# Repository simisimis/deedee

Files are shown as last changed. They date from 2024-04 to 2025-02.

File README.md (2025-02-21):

# DeeDee

A 36+2 key split monoblock ortholinear keyboard

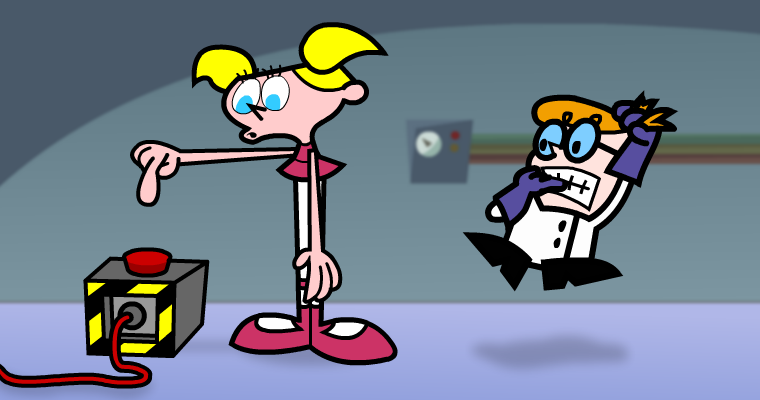
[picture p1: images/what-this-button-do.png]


## Current progress:

- [x] Key matrix
- [x] Layout defined
- [x] Addressable LEDs
- [x] Rotary encoders
- [ ] SSD1306 OLED screen
- [ ] Cirque touchpad
- [ ] Case design

A place where I try to document every step of the process is journalled in my [Project blog posts](https://github.com/simisimis/project-blog/tree/main/projects/DIY-keyboard) repo.

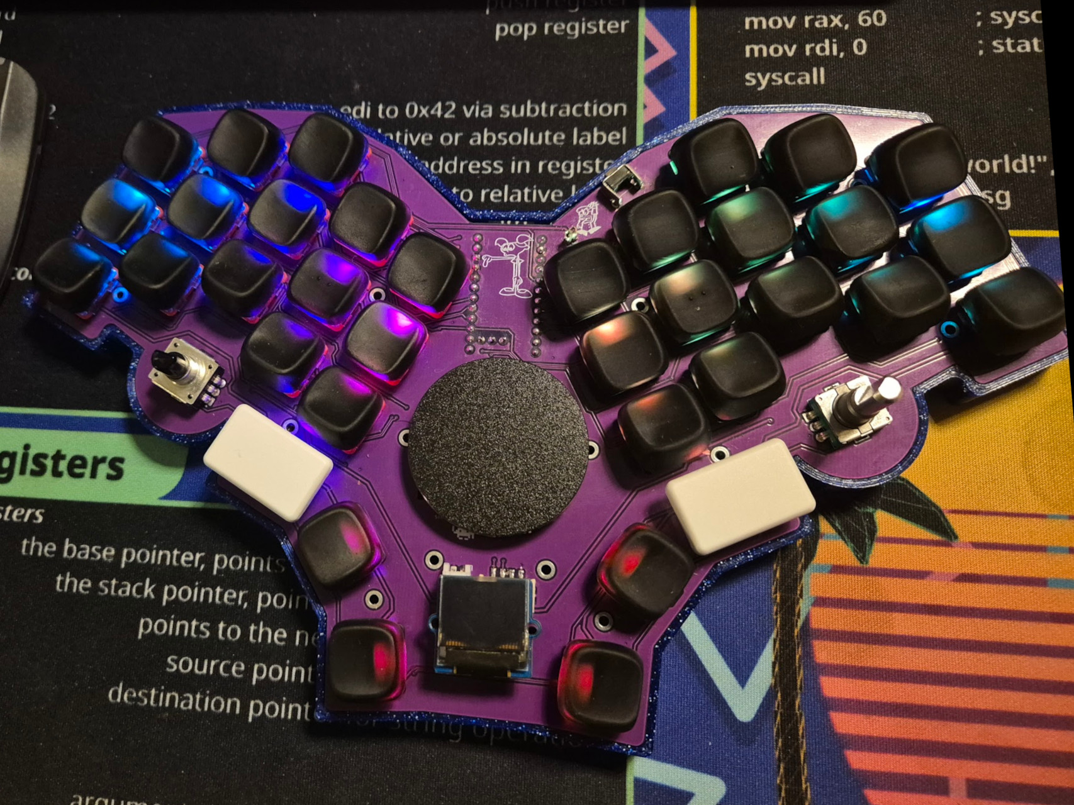
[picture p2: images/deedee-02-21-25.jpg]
In progress


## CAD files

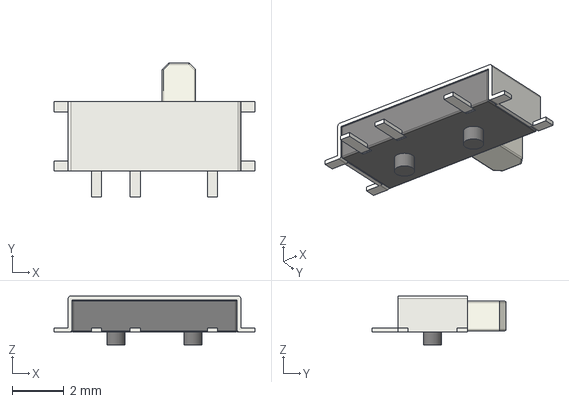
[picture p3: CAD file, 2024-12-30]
kicad/3dmodels/SW_MSK12C02.step
7.80 x 5.20 x 1.90 mm

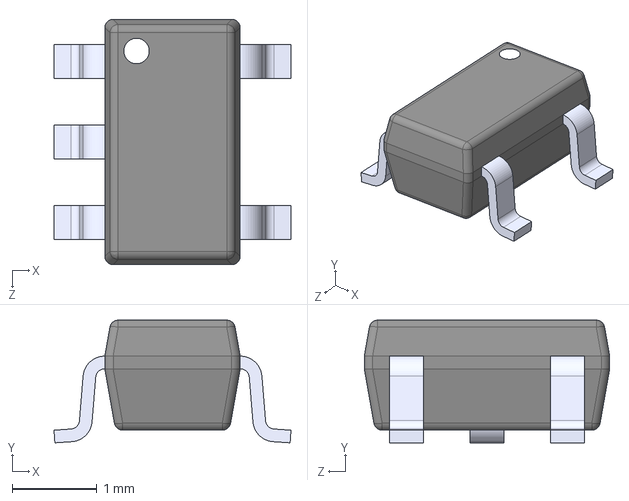
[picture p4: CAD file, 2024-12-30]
kicad/3dmodels/SN74LV1T34DBVR.step
2.80 x 1.45 x 2.90 mm

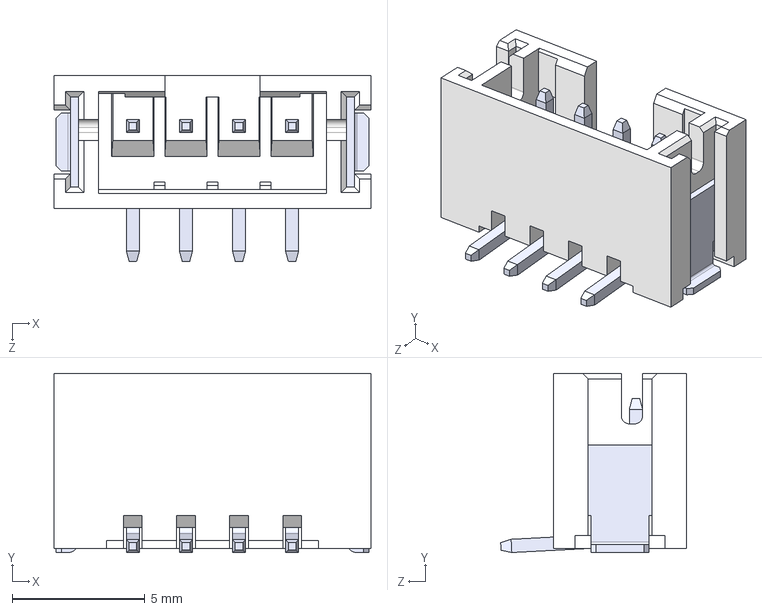
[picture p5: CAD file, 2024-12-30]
kicad/3dmodels/B4B-PH-SM4-TB__LF__SN_.step
12.0 x 6.75 x 7.00 mm

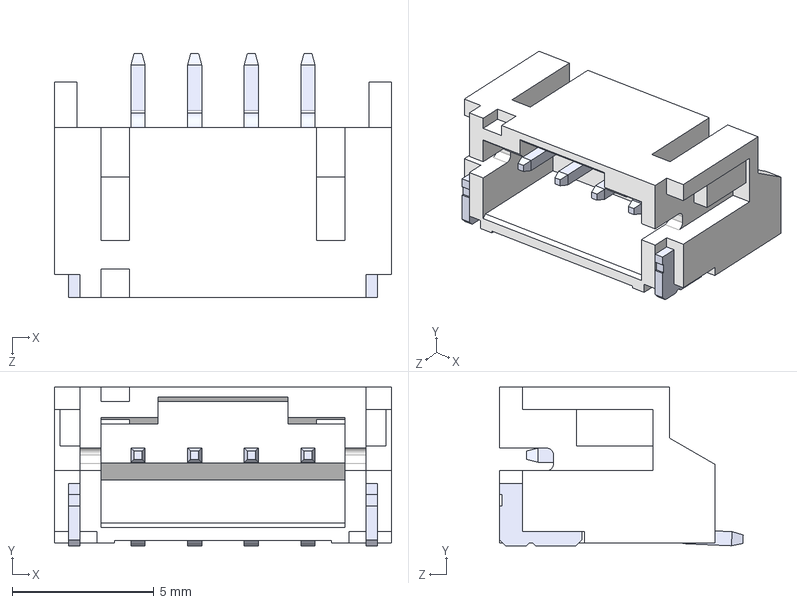
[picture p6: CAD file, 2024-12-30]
kicad/3dmodels/S4B-PH-SM4-TB.step
11.9 x 5.60 x 8.60 mm

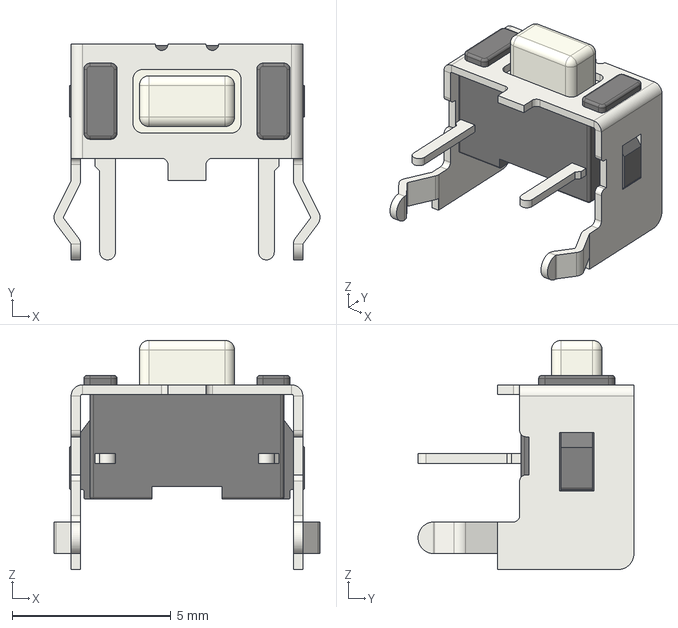
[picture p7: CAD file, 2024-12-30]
kicad/3dmodels/SW_SKHLLC.step
8.38 x 6.80 x 7.22 mm

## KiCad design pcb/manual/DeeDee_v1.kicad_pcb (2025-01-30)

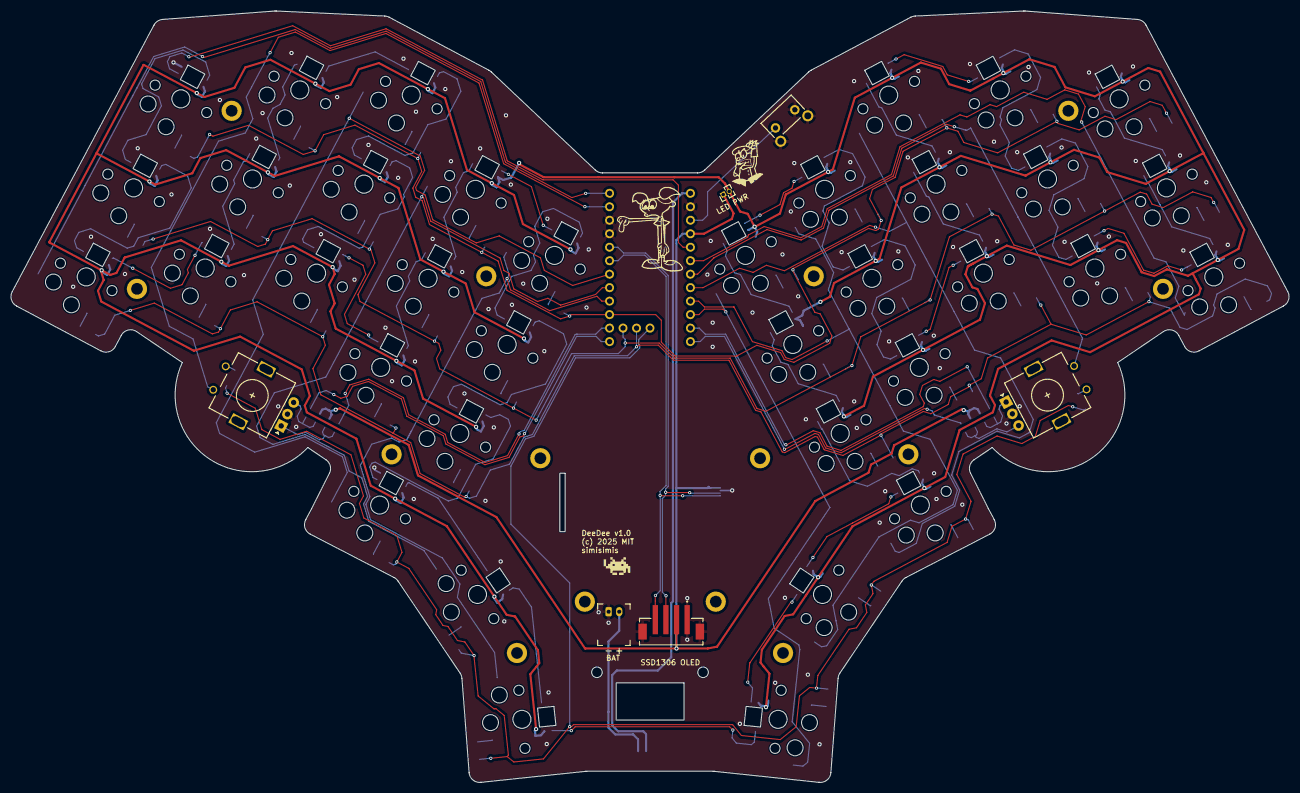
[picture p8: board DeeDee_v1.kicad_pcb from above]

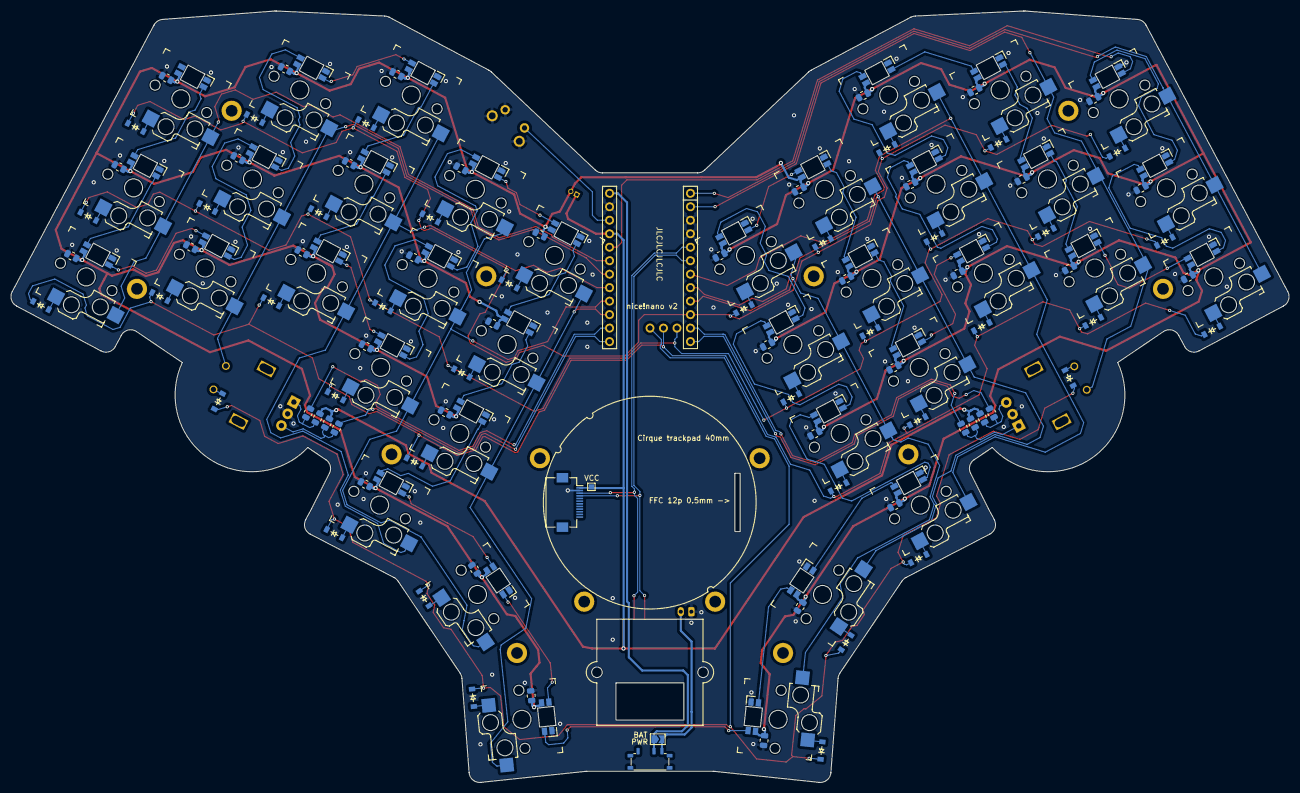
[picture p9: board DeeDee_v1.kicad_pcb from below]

Board: 2 copper layers, 240.8 x 145.3 mm, 169 parts (114 on the bottom side), 103 nets.

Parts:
BAT: battery_connector_jst_ph_2
BAT#2: SolderJumper-2_P1.3mm_Open_TrianglePad1.0x1.5mm
Cirque trackpad 40mm: FFC 12p 0.5mm; cirque_connector_12p_back
D1, D2, D3, D4, D5, D6, D7, D8, D9, D10, D11, D12, D13, D14, D15, D16, D17, D18, D19, D20, D21, D22, D23, D24, D25, D26, D27, D28, D29, D30, D31, D32, D33, D34, D35, D36, D37, D38: diode_tht_sod123
H1, H2, H3, H4, H5, H6, H7, H8, H8#2, H8#3, H9, H10: mounting_hole_plated
LED1, LED2, LED3, LED4, LED5, LED6, LED7, LED8, LED9, LED10, LED11, LED12, LED13, LED14, LED15, LED16, LED17, LED18, LED19, LED20, LED21, LED22, LED23, LED24, LED25, LED26, LED27, LED28, LED29, LED30, LED31, LED32, LED33, LED34, LED35, LED36: led_SK6812mini-e (per-keysingle-side)
LED PWR: PinHeader_1x02_P1.27mm_Vertical
MCU1: mcu_nice_nano
ROT1, ROT2: rotary_encoder
S1, S2, S3, S4, S5, S6, S7, S8, S9, S10, S11, S12, S13, S14, S15, S16, S17, S18, S19, S20, S21, S22, S23, S24, S25, S26, S27, S28, S29, S30, S31, S32, S33, S34, S35, S36: switch_choc_v1_v2
SMD1, SMD2, SMD3, SMD4, SMD5, SMD6, SMD7, SMD8, SMD9, SMD10, SMD11, SMD12, SMD13, SMD14, SMD15, SMD16, SMD17, SMD18, SMD19, SMD20, SMD21, SMD22, SMD23, SMD24, SMD25, SMD26, SMD27, SMD28, SMD29, SMD30, SMD31, SMD32, SMD33, SMD34, SMD35, SMD36, SMD37, SMD38: smd_805
SSD1306 OLED: SSD1306 OLED; jst-ph-smt-4p-2mm
VCC: TestPoint_Pad_1.0x1.0mm

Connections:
BAT_P: BAT.2, BAT#2.2
C1: MCU1.24, S1.2, S2.2, S3.2
C2: MCU1.23, ROT1.1, S4.2, S5.2, S6.2
C3: MCU1.18, S7.2, S8.2, S9.2, S31.2
C4: MCU1.17, S10.2, S11.2, S12.2, S32.2
C5: MCU1.16, S13.2, S14.2, S15.2, S33.2
C6: MCU1.10, S28.2, S29.2, S30.2, S36.2
C7: MCU1.9, S25.2, S26.2, S27.2, S35.2
C8: MCU1.8, S22.2, S23.2, S24.2, S34.2
C9: MCU1.7, ROT2.1, S19.2, S20.2, S21.2
C10: MCU1.6, S16.2, S17.2, S18.2
ELA: MCU1.14, SMD1.8
ELA_R: ROT1.A, SMD1.5, SMD1.7
ELB: MCU1.13, SMD1.2
ELB_R: ROT1.B, SMD1.1, SMD1.3
ERA: MCU1.11, SMD2.8
ERA_R: ROT2.A, SMD2.5, SMD2.7
ERB: MCU1.12, SMD2.2
ERB_R: ROT2.B, SMD2.1, SMD2.3
GND: BAT.1, Cirque trackpad 40mm.11, LED1.3, LED2.3, LED3.3, LED4.3, LED5.3, LED6.3, LED7.3, LED8.3, LED9.3, LED10.3, LED11.3, LED12.3, LED13.3, LED14.3, LED15.3, LED16.3, LED17.3, LED18.3, LED19.3, LED20.3, LED21.3, LED22.3, LED23.3, LED24.3, LED25.3, LED26.3, LED27.3, LED28.3, LED29.3, LED30.3, LED31.3, LED32.3, LED33.3, LED34.3, LED35.3, LED36.3, MCU1.2, MCU1.21, MCU1.22, ROT1.C, ROT2.C, SMD3.1, SMD4.1, SMD5.1, SMD6.1, SMD7.1, SMD8.1, SMD9.1, SMD10.1, SMD11.1, SMD12.1, SMD13.1, SMD14.1, SMD15.1, SMD16.1, SMD17.1, SMD18.1, SMD19.1, SMD20.1, SMD21.2, SMD22.2, SMD23.2, SMD24.2, SMD25.2, SMD26.2, SMD27.2, SMD28.2, SMD29.2, SMD30.2, SMD31.2, SMD32.2, SMD33.2, SMD34.2, SMD35.2, SMD36.2, SMD37.2, SMD38.2, SSD1306 OLED.1, SSD1306 OLED.SH1, SSD1306 OLED.SH2
LED: LED3.4, MCU1.5
LED_1: LED2.4, LED3.2
LED_2: LED1.4, LED2.2
LED_3: LED1.2, LED4.4
LED_4: LED4.2, LED5.4
LED_5: LED5.2, LED6.4
LED_6: LED6.2, LED9.4
LED_7: LED8.4, LED9.2
LED_8: LED7.4, LED8.2
LED_9: LED7.2, LED10.4
LED_10: LED10.2, LED11.4
LED_11: LED11.2, LED12.4
LED_12: LED12.2, LED15.4
LED_13: LED14.4, LED15.2
LED_14: LED13.4, LED14.2
LED_15: LED13.2, LED16.4
LED_16: LED16.2, LED17.4
LED_17: LED17.2, LED18.4
LED_18: LED18.2, LED36.4
LED_19: LED35.4, LED36.2
LED_20: LED34.4, LED35.2
LED_21: LED31.4, LED34.2
LED_22: LED31.2, LED32.4
LED_23: LED32.2, LED33.4
LED_24: LED30.4, LED33.2
LED_25: LED29.4, LED30.2
LED_26: LED28.4, LED29.2
LED_27: LED25.4, LED28.2
LED_28: LED25.2, LED26.4
LED_29: LED26.2, LED27.4
LED_30: LED24.4, LED27.2
LED_31: LED23.4, LED24.2
LED_32: LED22.4, LED23.2
LED_33: LED19.4, LED22.2
LED_34: LED19.2, LED20.4
LED_35: LED20.2, LED21.4
R1: D3.1, D6.1, D9.1, D12.1, D15.1, D22.1, D25.1, D28.1, D31.1, D34.1, MCU1.15
R2: D2.1, D5.1, D8.1, D11.1, D14.1, D21.1, D24.1, D27.1, D30.1, D33.1, MCU1.25
R3: D1.1, D4.1, D7.1, D10.1, D13.1, D20.1, D23.1, D26.1, D29.1, D32.1, MCU1.26
R4: D16.1, D17.1, D18.1, D19.1, D35.1, D36.1, D37.1, D38.1, MCU1.27
RAW: BAT#2.1, MCU1.1
SCL: Cirque trackpad 40mm.9, MCU1.19, SSD1306 OLED.4
SDA: Cirque trackpad 40mm.10, MCU1.20, SSD1306 OLED.3
VCC: Cirque trackpad 40mm.12, LED PWR.1, MCU1.4, SMD1.4, SMD1.6, SMD2.4, SMD2.6, SSD1306 OLED.2, VCC.1
VCC_LED: LED1.1, LED2.1, LED3.1, LED4.1, LED5.1, LED6.1, LED7.1, LED8.1, LED9.1, LED10.1, LED11.1, LED12.1, LED13.1, LED14.1, LED15.1, LED16.1, LED17.1, LED18.1, LED19.1, LED20.1, LED21.1, LED22.1, LED23.1, LED24.1, LED25.1, LED26.1, LED27.1, LED28.1, LED29.1, LED30.1, LED31.1, LED32.1, LED33.1, LED34.1, LED35.1, LED36.1, LED PWR.2, SMD3.2, SMD4.2, SMD5.2, SMD6.2, SMD7.2, SMD8.2, SMD9.2, SMD10.2, SMD11.2, SMD12.2, SMD13.2, SMD14.2, SMD15.2, SMD16.2, SMD17.2, SMD18.2, SMD19.2, SMD20.2, SMD21.1, SMD22.1, SMD23.1, SMD24.1, SMD25.1, SMD26.1, SMD27.1, SMD28.1, SMD29.1, SMD30.1, SMD31.1, SMD32.1, SMD33.1, SMD34.1, SMD35.1, SMD36.1, SMD37.1, SMD38.1
enc_enc: D19.2, ROT1.2
far_home: D18.2, S33.1
index_bottom: D10.2, S10.1
index_home: D11.2, S11.1
index_top: D12.2, S12.1
inner_bottom: D13.2, S13.1
inner_home: D14.2, S14.1
inner_top: D15.2, S15.1
mid_home: D17.2, S32.1
middle_bottom: D7.2, S7.1
middle_home: D8.2, S8.1
middle_top: D9.2, S9.1
mirror_enc_enc: D38.2, ROT2.2
mirror_far_home: D37.2, S36.1
mirror_index_bottom: D29.2, S25.1
mirror_index_home: D30.2, S26.1
mirror_index_top: D31.2, S27.1
mirror_inner_bottom: D32.2, S28.1
mirror_inner_home: D33.2, S29.1
mirror_inner_top: D34.2, S30.1
mirror_mid_home: D36.2, S35.1
mirror_middle_bottom: D26.2, S22.1
mirror_middle_home: D27.2, S23.1
mirror_middle_top: D28.2, S24.1
mirror_near_home: D35.2, S34.1
mirror_pinky_bottom: D20.2, S16.1
mirror_pinky_home: D21.2, S17.1
mirror_pinky_top: D22.2, S18.1
mirror_ring_bottom: D23.2, S19.1
mirror_ring_home: D24.2, S20.1
mirror_ring_top: D25.2, S21.1
near_home: D16.2, S31.1
pinky_bottom: D1.2, S1.1
pinky_home: D2.2, S2.1
pinky_top: D3.2, S3.1
ring_bottom: D4.2, S4.1
ring_home: D5.2, S5.1
ring_top: D6.2, S6.1

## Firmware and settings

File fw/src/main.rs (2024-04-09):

#![no_main]
#![no_std]

//#![allow(deprecated)] // to suppress "warning: use of deprecated item ... Users should use the traits in digital::v2.""

use core::panic::PanicInfo;
use cortex_m::asm;
use cortex_m_rt::entry;

use embedded_hal::digital::OutputPin;
use nrf52840_hal::gpio::*;
use nrf52840_hal::pac::Peripherals;

#[panic_handler]
fn panic(_info: &PanicInfo) -> ! {
    loop {
        asm::bkpt();
    }
}

#[entry]
fn main() -> ! {
    let p = Peripherals::take().unwrap();
    let p0 = p0::Parts::new(p.P0);

    let mut led = p0.p0_15.into_push_pull_output(Level::Low).degrade();

    loop {
        led.set_high().unwrap();
        asm::delay(10000000);
        led.set_low().unwrap();
        asm::delay(40000000);
    }
}

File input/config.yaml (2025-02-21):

units:
  # create switch dimensions from Kailh Choc
  kx: cx
  ky: cy
  # Padding Variables
  px: kx + 4
  py: ky + 5
  # Parts
  trackpad_radius: 20
  #encoder radius + dimensions
  enc_radius: 11
  encx: 22
  ency: 22
  # diode position + rotation
  diode_x: 5
  diode_y: -8.75
  diode_rotate: 180
  # LED position + rotation
  led_pos_x: 0
  led_pos_y: 4.7
  led_rotation: 0
  # Cases/Outlines variables
  dpx: px+4
  dpy: py+4
  screwRadius: 1.5
  standoffRadius: 3.5
  $default_padding: 19
  $default_spread: 19
  $default_width: 18
  $default_height: 17

points:
  zones:
    matrix:
      mirror: &mirror
        ref: matrix_inner_top
        distance: 2kx
      # Fix placement on KiCAD sheet.
      anchor:
        shift: [100, -100]
        rotate: -28
      columns:
        pinky:
          key:
            column_net: C1
            mirror.column_net: C10
          rows:
            top.key:
              led_prev: LED
              led_next: LED_1
            home.key:
              led_prev: LED_1
              led_next: LED_2
            bottom.key:
              led_prev: LED_2
              led_next: LED_3
            top.mirror.key:
              led_prev: LED_35
              led_next: LED_36
            home.mirror.key:
              led_prev: LED_34
              led_next: LED_35
            bottom.mirror.key:
              led_prev: LED_33
              led_next: LED_34
        ring:
          key:
            column_net: C2
            mirror.column_net: C9
            origin: [-12, -19]
            stagger: 12
          rows:
            top.key:
              led_prev: LED_5
              led_next: LED_6
            home.key:
              led_prev: LED_4
              led_next: LED_5
            bottom.key:
              led_prev: LED_3
              led_next: LED_4
            top.mirror.key:
              led_prev: LED_30
              led_next: LED_31
            home.mirror.key:
              led_prev: LED_31
              led_next: LED_32
            bottom.mirror.key:
              led_prev: LED_32
              led_next: LED_33
        middle:
          key:
            column_net: C3
            mirror.column_net: C8
            stagger: 9
          rows:
            top.key:
              led_prev: LED_6
              led_next: LED_7
            home.key:
              led_prev: LED_7
              led_next: LED_8
            bottom.key:
              led_prev: LED_8
              led_next: LED_9
            top.mirror.key:
              led_prev: LED_29
              led_next: LED_30
            home.mirror.key:
              led_prev: LED_28
              led_next: LED_29
            bottom.mirror.key:
              led_prev: LED_27
              led_next: LED_28
        index:
          key:
            column_net: C4
            mirror.column_net: C7
            stagger: -10
          rows:
            top.key:
              led_prev: LED_11
              led_next: LED_12
            home.key:
              led_prev: LED_10
              led_next: LED_11
            bottom.key:
              led_prev: LED_9
              led_next: LED_10
            top.mirror.key:
              led_prev: LED_24
              led_next: LED_25
            home.mirror.key:
              led_prev: LED_25
              led_next: LED_26
            bottom.mirror.key:
              led_prev: LED_26
              led_next: LED_27
        inner:
          key:
            column_net: C5
            mirror.column_net: C6
            stagger: -4
          rows:
            top.key:
              led_prev: LED_12
              led_next: LED_13
            home.key:
              led_prev: LED_13
              led_next: LED_14
            bottom.key:
              led_prev: LED_14
              led_next: LED_15
            top.mirror.key:
              led_prev: LED_23
              led_next: LED_24
            home.mirror.key:
              led_prev: LED_22
              led_next: LED_23
            bottom.mirror.key:
              led_prev: LED_21
              led_next: LED_22
      rows:
        bottom:
          row_net: R3
        home:
          row_net: R2
        top:
          row_net: R1
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

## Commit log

2024-04-23 checkpoint for board with keys/diodes/mcu/rotary
2024-11-19 picking up after the break
    [DeeDee_cp.kicad_pcb]
2024-12-30 overdue commit of many parts
    [B4B-PH-SM4-TB__LF__SN_.step, S4B-PH-SM4-TB.step, SN74LV1T34DBVR.step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]
2025-01-30 rm backup file
    [DeeDee_cp.kicad_pcb]
2025-01-30 DeeDee v1 milestone
    [DeeDee_v1-B_Cu.gbl, DeeDee_v1-B_Mask.gbs, DeeDee_v1-B_Paste.gbp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]
2025-02-18 call local action adjust the paths Add zmk config for DeeDee Add DeeDee zmk conf enable logging for debugging fix row0 pin mapping try gpio1 instead of pro_micro to fix columns Fix screwholes. Add bo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
    [config.yaml]
2025-02-18 add ec12 encoder configuration
2025-02-21 tune EC11,EC12 encoders
2025-02-21 update ceoloide footprints

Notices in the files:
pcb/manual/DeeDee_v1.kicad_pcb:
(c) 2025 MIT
